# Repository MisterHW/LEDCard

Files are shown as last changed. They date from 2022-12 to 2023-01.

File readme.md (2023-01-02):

# LEDCard

A credit card - sized, slim Li-Ion battery powered LED ring light for better macro shots everywhere you go.

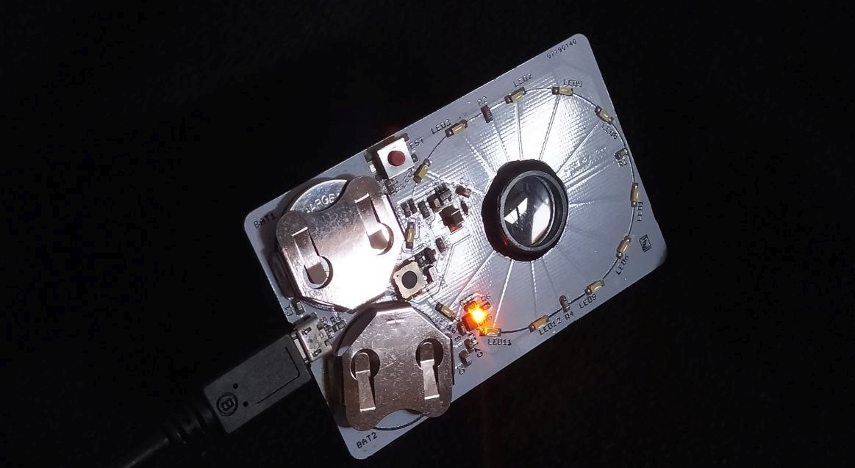
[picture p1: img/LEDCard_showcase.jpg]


## Revisions

Only revision 1E files (Eagle 7 format) were recovered at the time of this writing. Nevertheless, images and information about earlier versions are provided below to illustrate thoughts and decisions.

### LEDCard-1A : first prototype

Ideas:

- LED ring light
- macro lens
- battery-powered
- notches to be able to fix it to a device with rubber bands

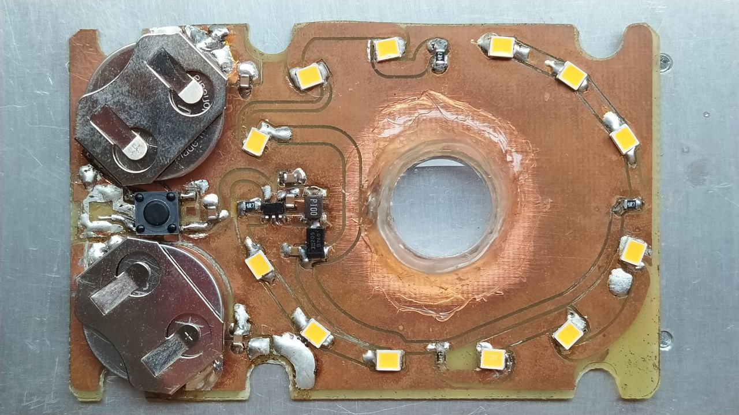
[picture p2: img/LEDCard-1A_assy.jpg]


Classic mistake: the photomask was flipped, so the SOT23-5 IC also had to be assembled on its back. Macro shot for entertainment purposes:

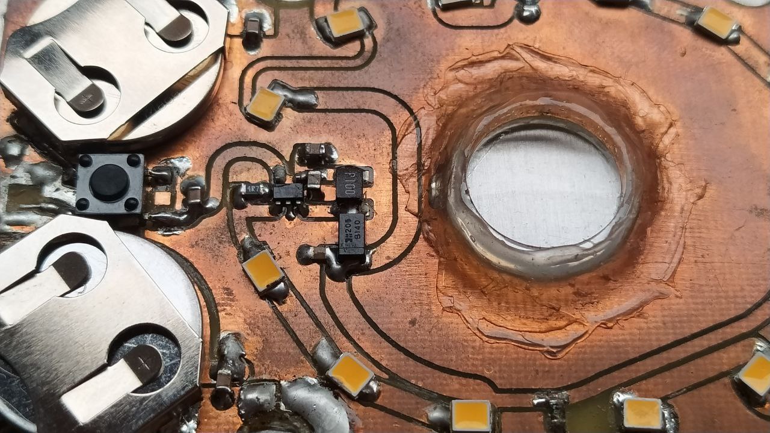
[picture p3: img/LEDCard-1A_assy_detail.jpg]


Insights:

- LED efficiency too low (~50 lm/W)
- CR2032 batteries inadequate
- Inrush current may lead to contact degradation of the push button over time.
- Rubber band idea turned out to be more of a fight than a feature. Covering the bottom side with tape may be more effective to prevent the board from sliding around on the smartphone. When combined with elastomeric protective cases, no additional material may be needed.

Switch from FAN5331 (Rds(ON) = 0.5 Ohm, 1.6 MHz) to LM3410Y (Rds(ON) = 0.17 Ohm, 0.525 MHz and 1.6 MHz options):

<table><thead><tr>
<td><a href="doc/FAN5331.pdf">FAN5331</a></td>
<td><a href="doc/LM3410.pdf">LM3410</a></td>
</tr></thead><tbody><tr>
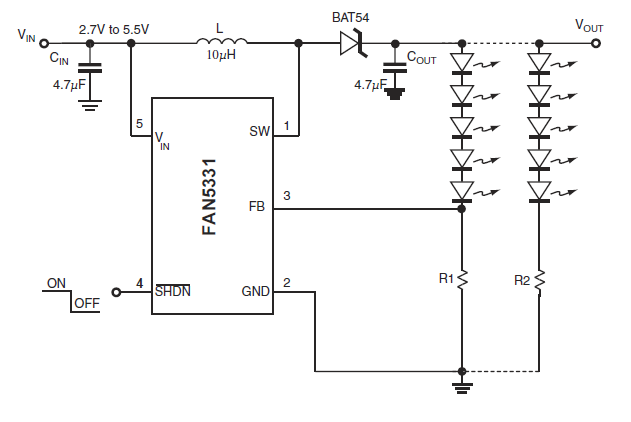
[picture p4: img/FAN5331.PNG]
<td></td>
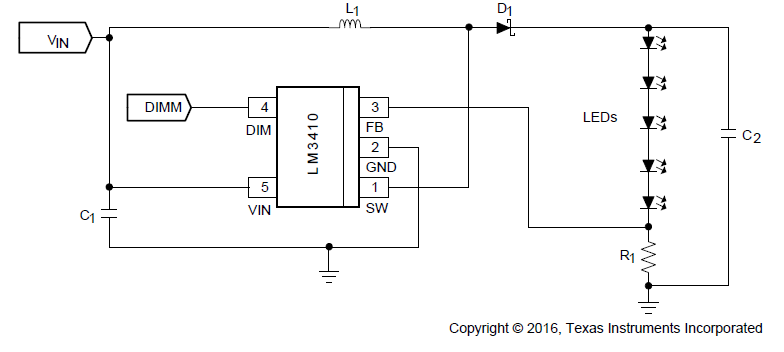
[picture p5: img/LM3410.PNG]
<td></td>
</tr></tbody></table>

### LEDCard-1D : LIR2430 cells and charging via USB

Ideas:
- Switch to LIR2430 rechargable Li-Ion button cells (60-70 mAh, Ichg = 50 mA, RS Part No.: 183-4294)
- Push button now switches ENA instead of VCC.
- Two power levels (ON / ON+HI) for medium and max brightness.
- Replace FAN5331 with LM3410.

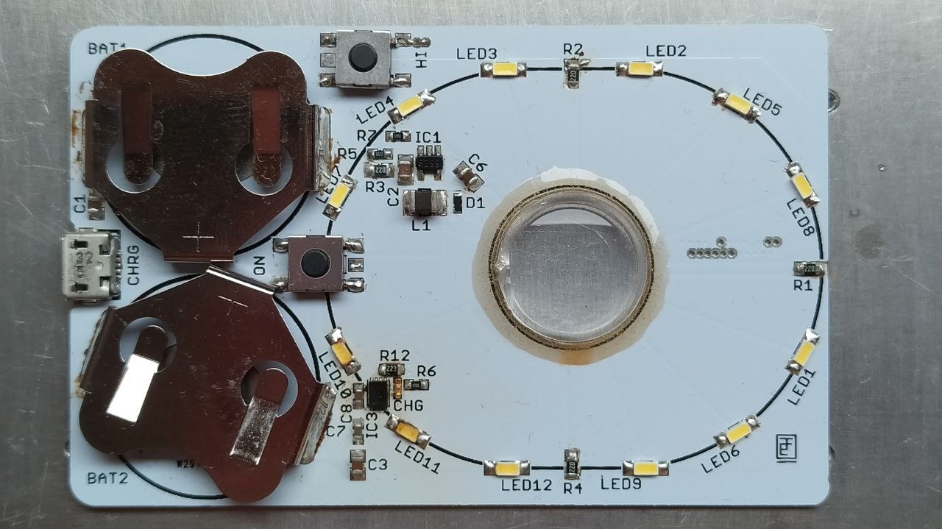
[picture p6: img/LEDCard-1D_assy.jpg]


Insights:

- Li-Ion cells can deep discharge and be destroyed.
- MCP73831 Li-Ion charging IC developed an intermittent solder joint failure after > 1 year of use in wallet, probably due to flexural stresses. Switch to MSOP recommended. Resolved by reflowing with pre-heater and hot air.
- 1.0mm FR4 is not stiff enough. Switch to 0.4mm or 0.6 mm FR4 and laminate onto laser-cut and deburred Ti sheet metal (see cad/ folder for .dxf file).
- ON button should raise MCP73831 charge current to allow USB-powered operation with a cable plugged in.

### LEDCard-1E : Battery Protection Update, Half-Press Button, Low Batt TEST

Ideas:

- Disable the boost converter when battery voltage under load drops below 2.5V (internal resistance is significant, maximum discharge current 2*60 mA is not great but can only be addressed with better / bigger cells or fragile pouch cells).
- Manage two power levels with a single push button that allows intuitive half / full press.
- Battery Level Test: half-press SW1 so the LED light turns on. When pressing TEST, the LEDs should turn off. Once they stay lit, the battery level is low. This works by forming a voltage divider to VCC. As VCC drops, FB is low enough to cause the boost converter to turn back on.
- TEST button at the edge does not cause the LEDCard to turn on when pressed accidentally.

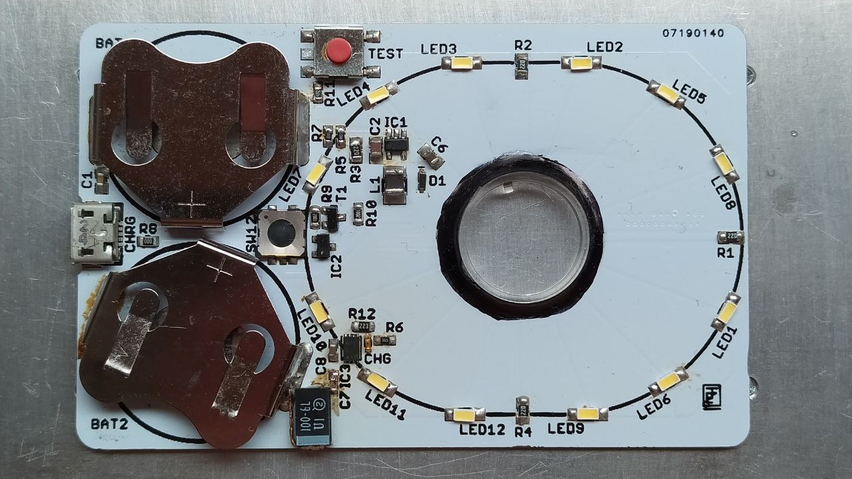
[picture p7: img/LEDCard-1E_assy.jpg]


Insights:

- Half press button is unpleasant, needs a printed / formed button cap to be useful. Idea to shield the button with battery clips around it is effective at preventing accidental presses, but also makes use harder.
- Tantalum capacitor in the picture was experimental and helped demonstrate that operation with USB connected is not possible without raising the charger current in LED on mode.
- SMD slider switch would be nice to enable continuous / hands-free operation (especially when USB is plugged in).
- USB-C to be considered for next iteration.
- LIR2430 cell found to be dead after 2 years of storage. Remove cells when not in use for > 4 weeks.
- FR4 front cover / diffusor would be nice. maybe 3D print with clear PETG?

#### LEDCard-1E Schematic

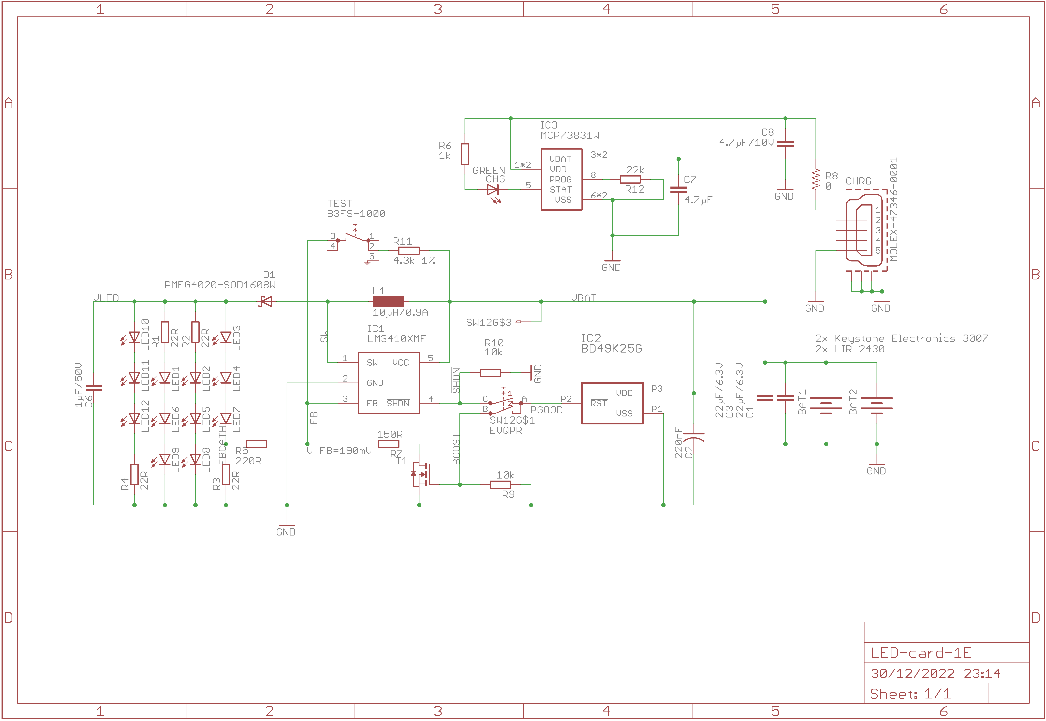
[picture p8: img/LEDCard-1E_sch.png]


#### LEDCard-1E Layout

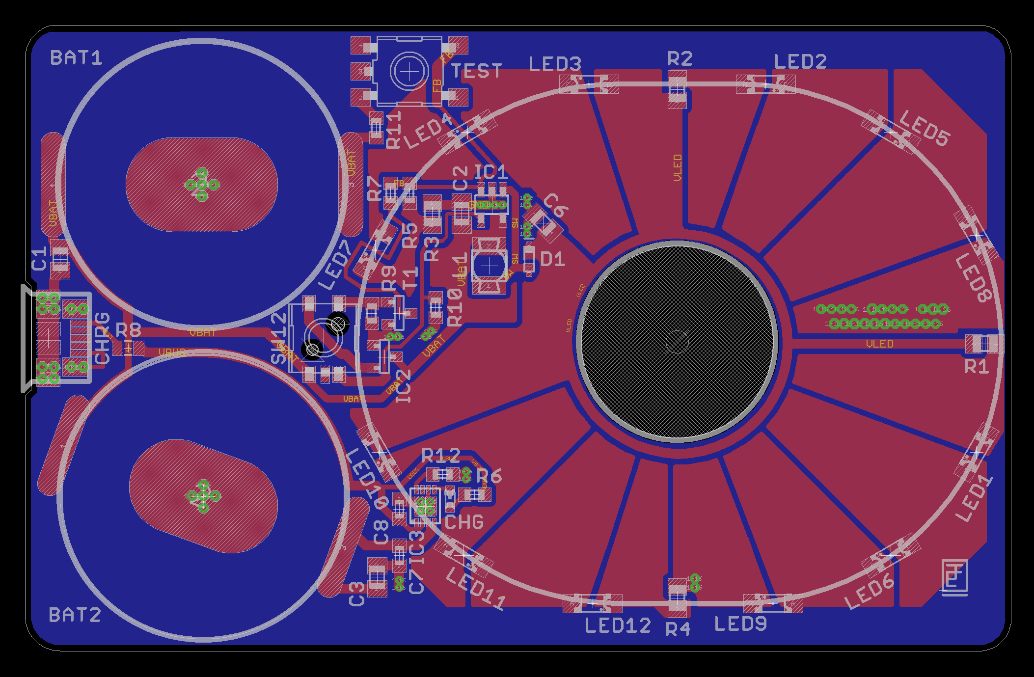
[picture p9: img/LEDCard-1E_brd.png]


#### Lenses

16.5mm diameter plano-convex molded acrylic lenses:

- f = +49 mm, https://astromedia.de/Opti-Media-Linse-OM4
- f = +65 mm, https://astromedia.de/Opti-Media-Linse-OM5
- f = +120 mm, https://astromedia.de/Opti-Media-Linse-OM6

Mounted with clear epoxy (Uhu Endfest). For mounting, put Al tape on the back of the LEDCard PCB and place the lens in its designated location. Rub the tape to get complete adhesion without air pockets to avoid seeping of the epoxy.

### Known Issues

Please see https://github.com/MisterHW/LEDCard/issues?q= where known problems are listed and improvements are discussed.

## License

Copyright Helge Wurst 2022.

This source describes Open Hardware and is licensed under the CERN-OHL-S v2.

You may redistribute and modify this source and make products using it under the terms of the CERN-OHL-S v2 (https://ohwr.org/cern_ohl_s_v2.txt).

This source is distributed WITHOUT ANY EXPRESS OR IMPLIED WARRANTY, INCLUDING OF MERCHANTABILITY, SATISFACTORY QUALITY AND FITNESS FOR A PARTICULAR PURPOSE. Please see the CERN-OHL-S v2 for applicable conditions.

Source location: https://github.com/MisterHW/LEDCard

As per CERN-OHL-S v2 section 4, should You produce hardware based on this source, You must where practicable maintain the Source Location visible on the external case of the Gizmo or other products you make using this source.

## Changes

* 2023-01: License information added.
* 2022-12: Project files recovered, documentation added. First release.
* 2017: Project started.

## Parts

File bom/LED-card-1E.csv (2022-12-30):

Qty | Value | Device | Package | Parts | Description | MF | MF_PARTNO | MOUSER | MPN | OC_FARNELL | OC_NEWARK | PN
2 |  | BATTERY | BATTCON_245MM | BAT1, BAT2 | Battery Holders | Keystone Electronics |  | 534-3007 | 3007
12 |  | LEDSML1206 | SML1206 | LED1, LED2, LED3, LED4, LED5, LED6, LED7, LED8, LED9, LED10, LED11, LED12 | LED | WE |  | 710-158301260 | 158301260
1 |  | NMOSSOT23 | SOT-23 | T1 | MOS FET |  |  |  |  | unknown | unknown
1 | 0 | RESISTOR0805-RES | 0805 | R8 | Resistor
2 | 10k | R-EU_R0603 | R0603 | R9, R10 | RESISTOR, European symbol
1 | 10µH/0.9A | MS50 | MS50 | L1 | INDUCTOR | Taiyo Yuden |  | CBC3225T100KR | CBC3225T100KR | unknown | unknown
1 | 150R | R-EU_R0603 | R0603 | R7 | RESISTOR, European symbol
1 | 1k | R-EU_R0603 | R0603 | R6 | RESISTOR, European symbol
1 | 1µF/50V | C-EUC0805K | C0805K | C6 | CAPACITOR, European symbol
1 | 220R | R-EU_R0603 | R0603 | R5 | RESISTOR, European symbol
1 | 220nF | C-USC0805K | C0805K | C2 | CAPACITOR, American symbol
4 | 22R | R-EU_R0805 | R0805 | R1, R2, R3, R4 | RESISTOR, European symbol
1 | 22k | R-EU_R0603 | R0603 | R12 | RESISTOR, European symbol
2 | 22µF/6.3V | C-EUC0805K | C0805K | C1, C3 | CAPACITOR, European symbol
1 | 4.3k 1% | R-EU_R0603 | R0603 | R11 | RESISTOR, European symbol
1 | 4.7µF | C-EUC0603K | C0603K | C7 | CAPACITOR, European symbol
1 | 4.7µF/10V | C-EUC0603K | C0603K | C8 | CAPACITOR, European symbol
1 | B3FS-1000 | SKHMPSE010 | SKHMPXE010 | TEST | 6.2 X 6.5mm TACT Switch (SMD) | OMRON |  | 653-B3FS-1000 | B3FS-1000
1 | BD49K25G | BD49K*G | SOT-23 | IC2 | Standard CMOS Voltage Detector IC
1 | EVQPR | EVQPR | EVQPR-GND | SW12 | Panasonic Light Touch Switches/EVQPR/Q0/3PR | PANASONIC | EVQ-PRHA09 | 667-EVQ-PRHA09
1 | GREEN | LEDCHIPLED-0603-TTW | CHIPLED-0603-TTW | CHG | LED
1 | LM3410XMF | FAN5333 | SOT23-5L | IC1 |  | Ti |  | 926-LM3410XMF/NOPB | LM3410XMF
1 | MCP73831W | MCP73831W | DFN8W | IC3 | Miniature Single-Cell, Fully Integrated Li-Ion,
1 | MOLEX-47346-0001 | MOLEX-47346-0001 | MOLEX-47364-0001 | CHRG | MICRO USB B, BOTTOM MOUNT
1 | PMEG4020-SOD1608W | PMEG4020-SOD1608W | SOD1608W | D1 | SOD123W Schottky Rectifier | Nexperia |  | 771-PMEG4020EPK,315 |  |  |  | PMEG4020EPK,315

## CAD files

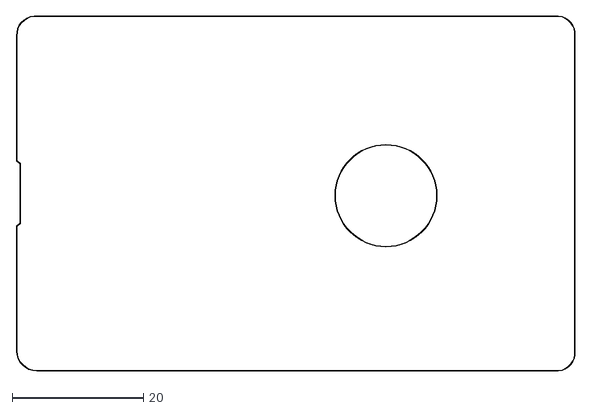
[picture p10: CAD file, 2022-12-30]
cad/LED-card-Ti.dxf
85.2 x 54.0

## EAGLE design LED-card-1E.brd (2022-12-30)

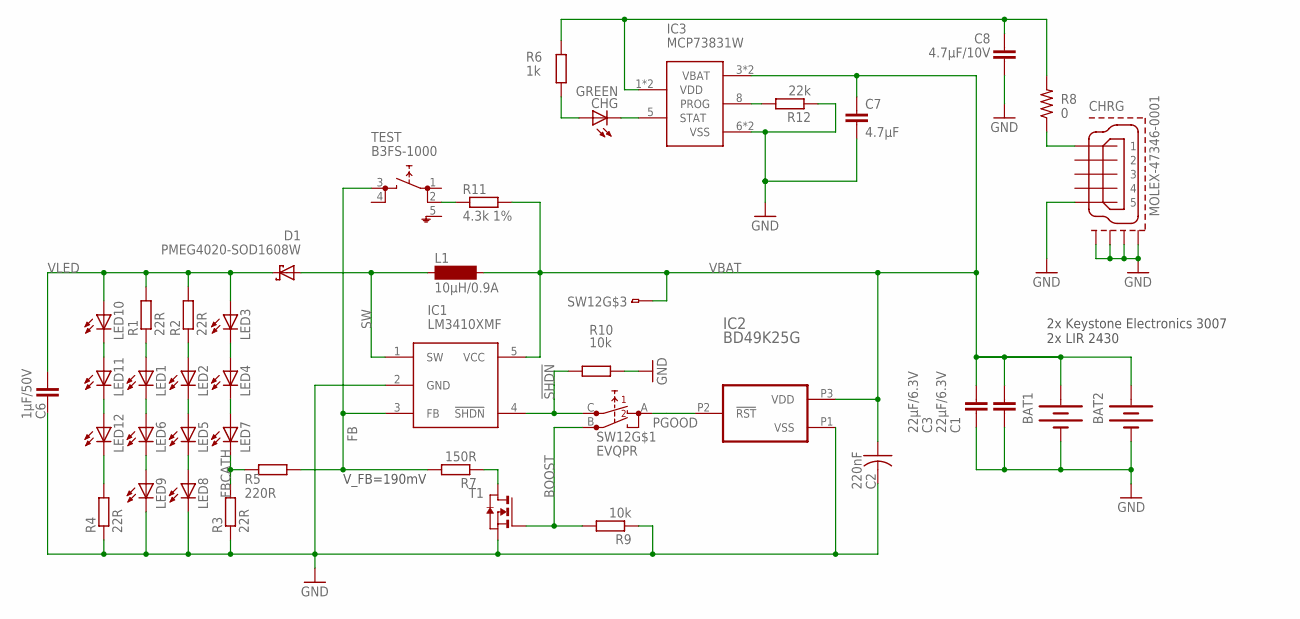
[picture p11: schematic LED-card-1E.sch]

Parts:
BAT1, BAT2: BATTERY; BATTCON_245MM; MPN 3007; MOUSER 534-3007
C1, C3: 22µF/6.3V; C0805K
C2: 220nF; C0805K
C6: 1µF/50V; C0805K
C7: 4.7µF; C0603K
C8: 4.7µF/10V; C0603K
CHG: GREEN; CHIPLED-0603-TTW
CHRG: MOLEX-47346-0001; MOLEX-47364-0001
D1: PMEG4020-SOD1608W; SOD1608W; MOUSER 771-PMEG4020EPK,315
IC1: LM3410XMF; SOT23-5L; MPN LM3410XMF; MOUSER 926-LM3410XMF/NOPB
IC2: BD49K25G; SOT-23
IC3: MCP73831W; DFN8W
L1: 10µH/0.9A; MS50; MPN CBC3225T100KR; MOUSER CBC3225T100KR
LED1, LED2, LED3, LED4, LED5, LED6, LED7, LED8, LED9, LED10, LED11, LED12: LEDSML1206; SML1206; MPN 158301260; MOUSER 710-158301260
R1, R2, R3, R4: 22R; R0805
R5: 220R; R0603
R6: 1k; R0603
R7: 150R; R0603
R8: 0; 0805
R9, R10: 10k; R0603
R11: 4.3k 1%; R0603
R12: 22k; R0603
SW12: EVQPR; EVQPR-GND; MF_PARTNO EVQ-PRHA09; MOUSER 667-EVQ-PRHA09
T1: NMOSSOT23; SOT-23
TEST: B3FS-1000; SKHMPXE010; MPN B3FS-1000; MOUSER 653-B3FS-1000

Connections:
!SHDN: IC1.4 (!SHDN), R10.1, SW12.C (1.1)
BOOST: R9.2, SW12.B (1.2), T1.3 (G)
FB: IC1.3 (FB), R5.1, R7.2, TEST.3 (2.1)
FBCATH: LED7.C, R3.2, R5.2
FBLO: R7.1, T1.1 (D)
GND: BAT1.2 (-), BAT2.2 (-), C1.2, C2.2, C3.2, C6.2, C7.2, C8.2, CHRG.5, CHRG.GND1, CHRG.GND2, CHRG.GND3, CHRG.GND4, IC1.2 (GND), IC2.P1 (VSS), IC3.6 (VSS), IC3.GND (VSS), LED8.C, LED9.C, R3.1, R4.1, R9.1, R10.2, R12.1, T1.2 (S)
unnamed: R11.1, TEST.2 (1.2)
unnamed: IC3.8 (PROG), R12.2
unnamed: LED1.A, R1.1
unnamed: LED3.C, LED4.A
unnamed: LED2.C, LED5.A
unnamed: LED1.C, LED6.A
unnamed: LED6.C, LED9.A
unnamed: LED5.C, LED8.A
unnamed: LED4.C, LED7.A
unnamed: CHG.C@1 (C), IC3.5 (STAT)
unnamed: LED2.A, R2.1
unnamed: CHG.A@1 (A), R6.1
unnamed: CHRG.1, R8.1
unnamed: LED10.C, LED11.A
unnamed: LED11.C, LED12.A
unnamed: LED12.C, R4.2
PGOOD: IC2.P2 (!RST), SW12.A (2.1)
SW: D1.A, D1.A2 (A), IC1.1 (SW), L1.1
VBAT: BAT1.1 (+), BAT1.3 (+), BAT2.1 (+), BAT2.3 (+), C1.1, C2.1, C3.1, C7.1, IC1.5 (VCC), IC2.P3 (VDD), IC3.3 (VBAT), IC3.4 (VBAT), L1.2, R11.2, SW12.D (1)
VBUS: C8.1, IC3.1 (VDD), IC3.2 (VDD), R6.2, R8.2
VLED: C6.1, D1.C, D1.C2 (C), LED3.A, LED10.A, R1.2, R2.2

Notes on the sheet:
2x Keystone Electronics 3007 2x LIR 2430
V_FB=190mV

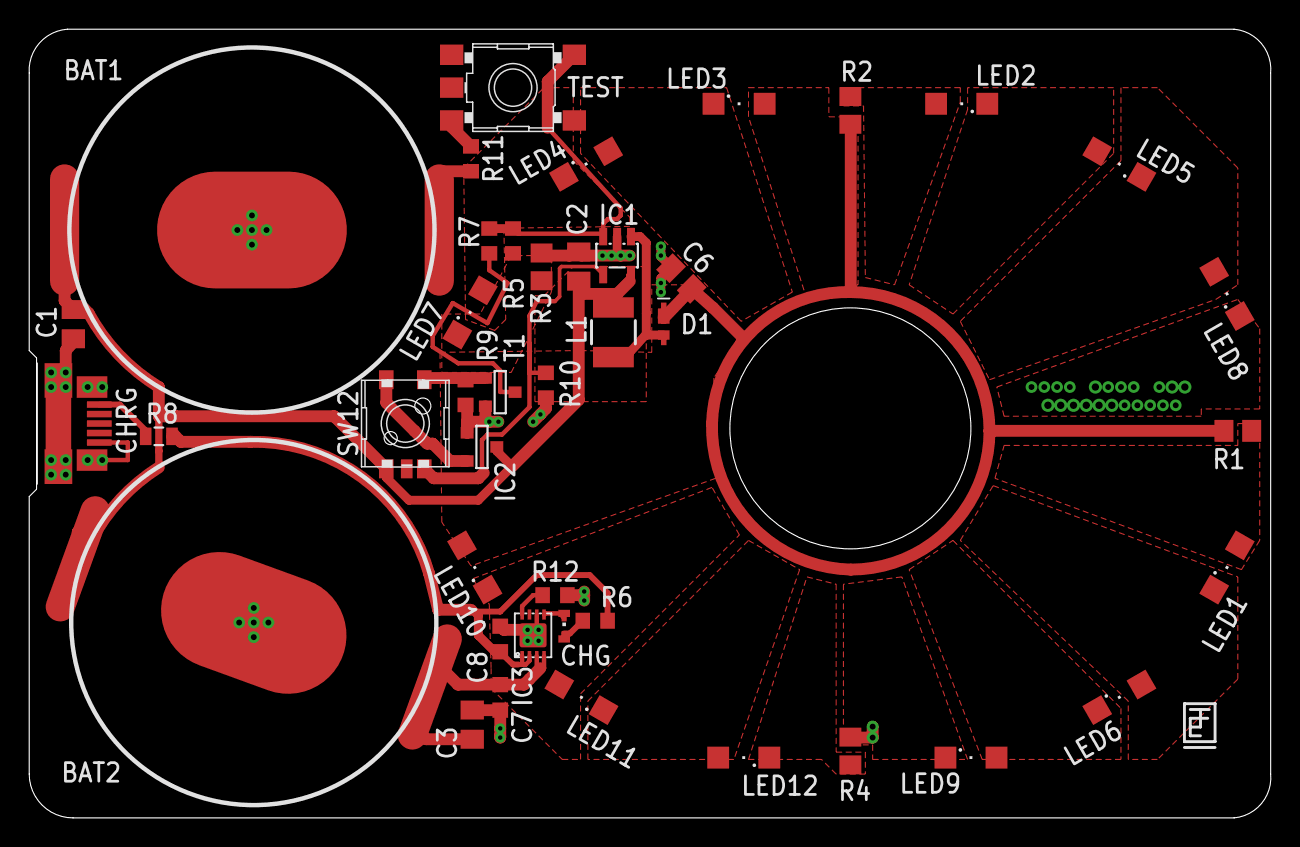
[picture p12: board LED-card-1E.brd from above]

Board: 2 copper layers, 85.0 x 54.0 mm, 43 parts (0 on the bottom side), 27 nets.

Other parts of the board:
U$1: DESIGNER

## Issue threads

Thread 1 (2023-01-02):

Add license information

vazhnov, 2023-01-02:
Hello!

I found this project from https://hackaday.com/2023/01/01/ledcard-the-pocketable-ring-light/

Could you please add information about the license of this repository — is it allowed to copy, change and use the code and PCB files in any purpose? (except of `doc` directory, I think).
It would be great to see any popular open source license.

MisterHW, 2023-01-02:
Hello,

I've added OHL-S v2 license information. The supplemental documents are obviously not my work but added for educational purposes as differences between these parts are discussed and the reader is expected to need to look them up, which should be covered under fair use (plus, I'm as tired as everyone to continuously go and hunt down datasheets and errata).
As a pro-forma statement, the reader should also check the manufacturers' websites for the latest version of the documents.

Issue resolved though https://github.com/MisterHW/LEDCard/commit/1b5f86fcf28a68698b8123f808d86395ac07e062

Closed 2023-01-02.

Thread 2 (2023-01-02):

test status is opposite to what i'd expect

erffrfez, 2023-01-02:
having the LED turn off if the battery is good, and stay on if it needs charging seems "the wrong way around" to me.
Can you swap the "legs" of the voltage divider that this uses, to make the light turn off on test if the battery is low?
(or something else with the same effect)

best wishes

MisterHW, 2023-01-02:
Interesting point. Hand tool batteries have bar indicators with 3 or 4 LEDs that show the state of charge upon the press of a button, and one should pay tribute to that pattern where possible.

As there are already some white LEDs on board, one could, for example, connect the `TEST` button and resistor between the last LED in a chain and the positive battery rail. It would then give an indication of the charge level of the battery and dim gradually to only give a faint glow when the battery is depleted - much like the very cheap button cell keychain lights that connect a white LED straight to a tiny button cell. The downside is that if the button happens to be pushed during transport, it will deplete the batteries.

The way the LEDCard battery indicator works is as follows:
`TEST` pulls the feedback pin towards the battery voltage needing to be measured. A high enough `FB` voltage created by the resulting voltage divider therefore overcomes the threshold and disables the boost converter. A low battery voltage allows the converter to drive the LEDs at a reduced current, but there is also some desirable positive feedback - as under load the battery voltage drops further.

To achieve an inverted effect (battery low = LED off), the `FB` side is probably not a good place. Admittedly, the `TEST` feature was implemented between revisions, with the ULVO detection added later. As a potential solution to this issue, one could use a push button switch to connect a voltage divider to GND and run BD49xxx off that divider. Pushing the button would then scale the battery voltage down with an adjustable factor and give a precise threshold.
The only catch I can see right there would be that once again a way to accidentally deep discharge the cells during transport is created - this time via resistors. BD49xxx Iq = 0.9 µA + LM3410 Ileak = 0.1 µA is helpful tough, as one could choose the upper resistor to be 10-50 K for 10-50 mV error, making the overall divider high impedance, and the discharge current a matter of < 10 µA when pressed accidentally.

MisterHW, 2023-01-02:
Battery test definitely needs to be changed, as currently the ~ 4.5k discharge path will also drain and destroy the cells.

* Minimum fix: **Connect TEST to BD49xxx output**, which tracks the VBAT while cells are not depleted.
* For "batt low == LEDs off" logic, implement voltage divider as described above. Add conformal coating.

erffrfez, 2023-01-03:
thanks for the reply and best wishes with your project, it looks good and I
hope I have helped in a small way

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

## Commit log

2022-12-30 initial release
    [LED-card-1E.brd, LED-card-1E.csv, LED-card-1E.sch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]
2022-12-31 append lens info

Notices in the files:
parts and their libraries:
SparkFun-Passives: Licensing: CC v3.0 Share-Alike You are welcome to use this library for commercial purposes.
